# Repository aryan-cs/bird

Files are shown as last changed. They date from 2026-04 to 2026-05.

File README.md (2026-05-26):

# bird

revisiting one of my high school senior thesis projects

[[timf](https://aryan-cs.github.io/bird/timf.pdf)] [[rcgroup](https://www.rcgroups.com/forums/showthread.php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)] [[files](https://aryan-cs.github.io/bird)] [[repo](https://github.com/aryan-cs/bird)]

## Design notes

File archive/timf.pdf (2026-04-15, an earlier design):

# 3D Print F22 Raptor by TimF

Created | V1 | July 2021 | Original issue
Current Revision | V3 | 13th October 2022 | Scale shaping, tail reinforcements, sacrificial stab tips

A big thanks for your interest and for downloading this design

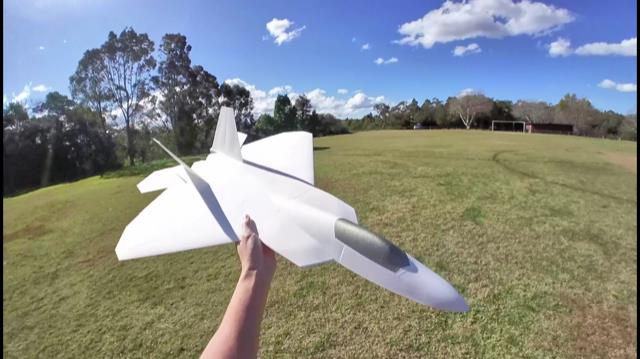
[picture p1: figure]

I’m a mechanical engineer and an RC enthusiast for over 30 years. I’ve also completed full-size pilot qualifications that have fallen to the side. Many dozens of kits later ranging from balsa and tissue, ARF’s, 3D prints to mass produced foamies, I’ve finally been able to get around to designing a plane. I hope it, and subsequent designs can help fulfill the dream of designing printing and flying your own planes.

The Raptor is an amazing subject. I can only imagine the design effort and championing that has gone into it. Lots of respect for this and the engineers that have contributed to its fruition. My rendition is purely for RC and as an enthusiast. I hope it can capture some of the real thing.

If you are familiar with RC planes (especially 3D printed ones), ahead is a relatively quick and easy print with a low part count. It is meant for intermediate to advanced flyers. With a dialled in printer, the fabrication happens in a week with little effort. Jet models can mean tiny wings, blindingly fast roll rate and a small shape which can be hard to fly. I have designed it from the outset to address as many of these traps as possible. Here is support documentation for the print, assembly, and setup as best I can provide to date for the best chances of success. Please do ask questions, make recommendations, or log any issues:

RC Groups thread: https://www.rcgroups.com/forums/showthread.php?3931791-F22-Raptor-700mm-LW-PLA#post47446455 (https://www.rcgroups.com/forums/showthread.php?3931791-F22-Raptor-700mm-LW-PLA#post47446455)

## Materials

1. PLA, LW-PLA (Colorfab, 3DLabPrint etc.) is preferred. A 1.75mm direct drive extruder printer is ideal
2. 50mm EDF. FMS 50mm, XRP-50mm, XFly-Model 4600kV or similar
3. 4s 1300mAh 25C or above battery
4. 350mm 0.87-1mm piano wire pushrod x 2
5. RC gear, quick pushrod linkages x 2
6. 250mm 3x1mm carbon main spar pultruded strip (x2) + 55mm (x2) for rear sub spars (optional)
7. 60mm OD3mm carbon taileron axle rod (x2) (or filled tube)
8. Adhesive Velcro j/o
9. 40A esc or above to suit EDF
10. 2x 9g servos (+2x 8mm thick servos if using flaperons)
11. Servo extension leads
12. Optional: 10mm dia.’ magnets for nose (x2)
13. Thin CA type hinges (optional)
14. 3x small servo mount type screws for fan hatch
15. Twist wire (from $2 shop or similar) or 1mm sharpened carbon fibre skewers to pin control surfaces

## Tools

1. Step drill bits (fine increment)
2. Hand twist drill or Dremel
3. Coarse round file or rasp to clean stringing
4. Sandpaper
5. Z bend pliers or needle nose pliers
6. Needle files
7. Hobby knife, hot knife
8. Side cutters
9. Metal ruler

## Adhesives

1. I use Acrifix ™ 0192 to glue PLA main assemblies and foamie Welder’s Glue™ or UHU-Por™ for spars etc.
2. Alternatively, medium CA plus accelerator as a rule throughout
3. Thin CA for wicking joints

## Print Overview, Definitions and Weights

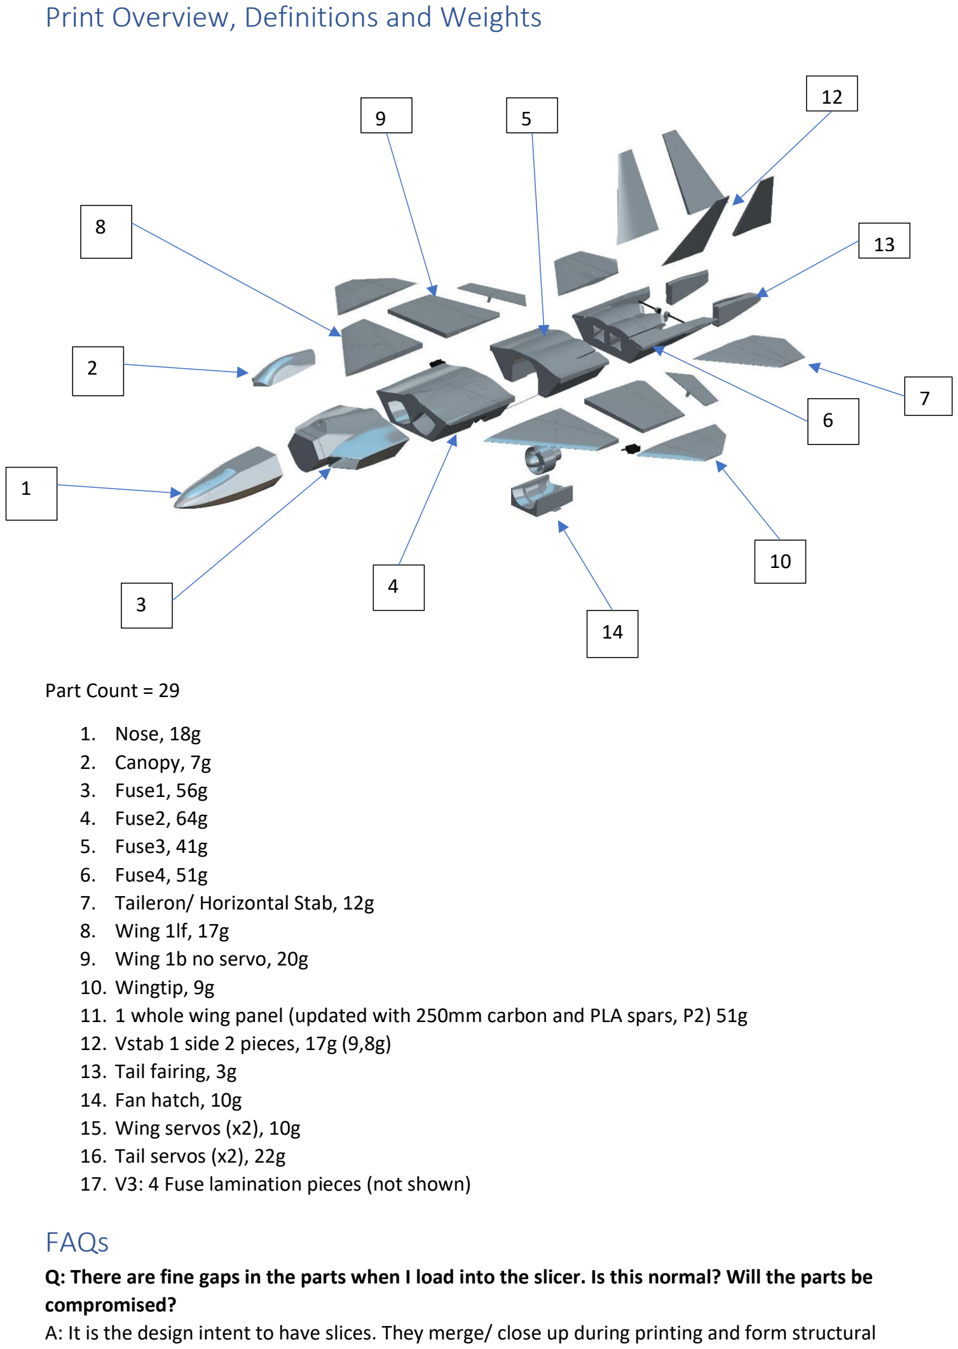
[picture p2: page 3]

Part Count = 29

1. Nose, 18g
2. Canopy, 7g
3. Fuse1, 56g
4. Fuse2, 64g
5. Fuse3, 41g
6. Fuse4, 51g
7. Taileron/ Horizontal Stab, 12g
8. Wing 1lf, 17g
9. Wing 1b no servo, 20g
10. Wingtip, 9g
11. 1 whole wing panel (updated with 250mm carbon and PLA spars, P2) 51g
12. Vstab 1 side 2 pieces, 17g (9,8g)
13. Tail fairing, 3g
14. Fan hatch, 10g
15. Wing servos (x2), 10g
16. Tail servos (x2), 22g
17. V3: 4 Fuse lamination pieces (not shown)

## FAQs

Q: There are fine gaps in the parts when I load into the slicer. Is this normal? Will the parts be compromised?
A: It is the design intent to have slices. They merge/ close up during printing and form structural

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
14 ribbing. If your extrusion is low, they will be more noticeable in the print. LW-PLA yields the best, strongest and lightest result as it foams, expands and merges during print. If unavoidable through print settings, run some thin CA glue in the gap and it will be even stronger

Q: Your parts look solid and un-usable

A: Slice with 0% infill (unless stated)

Q: The nose is a very tight fit

A: It is designed on the tight side in case some printers extrude differently and end up way too loose, so you might have to sand the corners slightly to achieve a snug fit. The material may relax a bit with use too so the intendent was to start off snug

Q: Which orientation to print the parts?

A: Refer to the table in printing section

## Configuration

There are 2 wing version:

1. Mandatory, 2 servos (i.e.: taileron/ elevon control)
2. Optional flaps + taileron 4 servos version. Flap to elevator mixing is in the radio control setup and throws section.

## Scaling

130%
If you want a slightly larger model, I have flown this model scaled up to 910mm wingspan, 1110g+battery weight.
1. 130% size in slicer program
2. 64mm EDF
3. 4S 2200 mAh Lipo
4. 4mm carbons in lieu of 3mm (solid rod is preferred over tube as handling damage can overtorque and split the carbon tubing)
5. 17g servos (30mm L) + 9g 8mm thick flap servos
6. 2% infill for wing 1f, horizontal stabs, wingtip, vstabs
7. Files from regular PLA version for wing 1r, horizontal stabs
8. Run fibre string through fuselage parts prior to joining to run servo cable extensions

## Printing

1. Print the parts with your best settings for LW-PLA/ PLA. LW-PLA is a foaming PLA material which is less than half the weight of standard PLA when printed properly. It has good layer adhesion due to expansion and foaming
2. Unless stated, print orientation for the parts is intended to be rear bulkheads/ wing root to build plate where possible. Look for any scribe lines which show where to cut after printing and align that surface to build plate
Part | Orientation (face) on print bed | Bottom Layers | Top layers
Sawtooth Nose | Rear | N | Y
Nose | Rear | N | Y

Fuse1 | Rear | Y | N
Fuse2 | Rear | Y | N
Fuse3 | Rear | Y | N
Fuse4 | Front | Y | Y
Wings | Root | Y | Y
Hatch | Front | Y | Y
Fairings | Inboard | Y | N
Tailerons | Root | Y | Y
Vertical Stabs | Rear and front | Y | Y
Flaps/ ailerons | Control horn | Y | Y
Hstab main | Root | Y | Y
HStab Front | Rear (rear, engraving down) | Y | Y
3. 2 walls of foaming LW-PLA. It is more expensive but worth using it as the parts are more resilient. You will get better results for your efforts, less transport damage and “tin canning” thanks to the extra wall
4. Narrow gaps-
5. If using regular non foaming PLA 1, wall is recommended as 2 walls will be too heavy
6. Good idea to start with the fan hatch print first off to check if your fan unit will need any cutting or wrapping with tape to fit in the bay
7. Print the rest of the parts starting with the nose, fuse1, 2. left wing, right wing etc.
8. The wing sections are very thin. Use an adhesive product such as Dimafix™ on the print bed or a brim to ensure they don’t get knocked over. The aileron CAD has been supplied with adhesion tabs to help. Trim these off with side cutters after printing
9. 0.4mm ‘Z hop when retracted’ to allow expansion flow and avoid knocking parts over
10. 0% infill unless essential or printing the 64mm version
11. Clean any stringing as much as possible with a rasp or long metal ruler edge
12. Parts that need knifing/ hot wire cutting afterward have the paths scribed/ indented. They are important for cable routing. Heat a wire and use it to cut the excess panel out or use several careful light cuts with a scalpel. Don’t forget, as it is a pain to do this afterwards
13. The taileron horns require a slight cooler printing temp (if using LW-PLA) to have less foaming effect and greater hardness/ precision. I use 220-225°C. as opposed to 230°C for the airframe

## Assembly

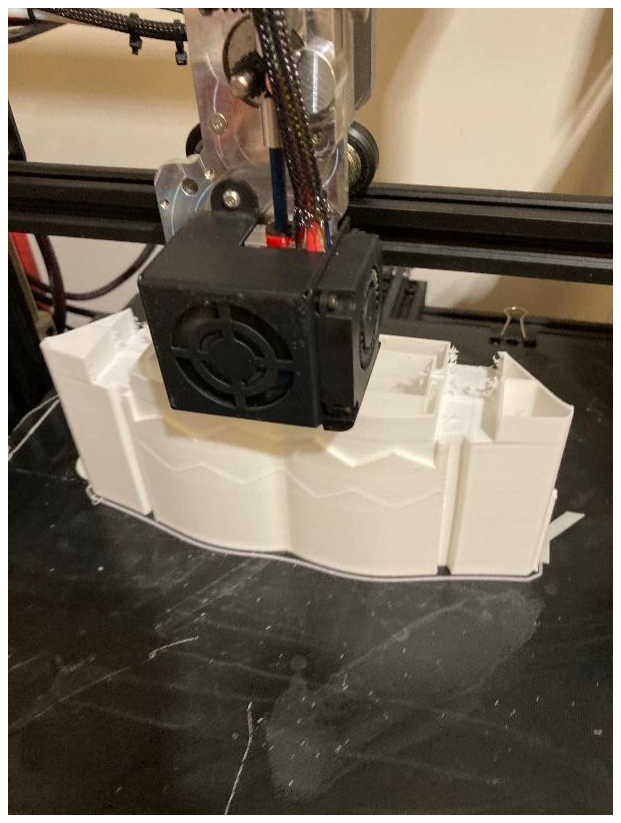
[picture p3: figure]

Start the fuselage assembly whilst the wings are printing.

1. Starting with the Fan hatch and Fuse3, cut open the motor wire and servo openings with a hot knife. Check your EDF fan unit fits. Wrap with masking tape/ cut plastic if needed. Install the unit in with UHU Por or Welders glue
2. Plug in the ESC, route the cables and ESC forward and make sure the fan spins in the correct direction when powered up (it should also be balanced for best results). Screw down the fan hatch. That’s the engine installation done!
3. Cut the marked cable routing panels for Fuse 2 out of the bottom and have the part ready
4. Cut 2x 250mm of the 0.81mm piano pushrod wire and thread it through the pushrod guides of Fuse 2 and Fuse 3. Make sure it slides freely. Use it as an alignment aid to help glue the fuse together (Medium CA or Acrifix). Don’t use excessive glue, and don’t glue the fan hatch to Fuse 2!

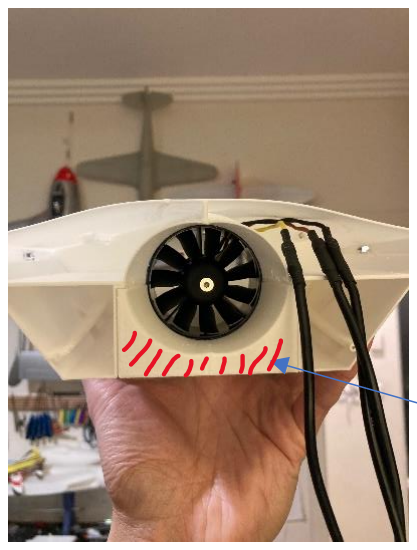
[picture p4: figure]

5. Glue Fuse 4 using the same method

No glue!

6.

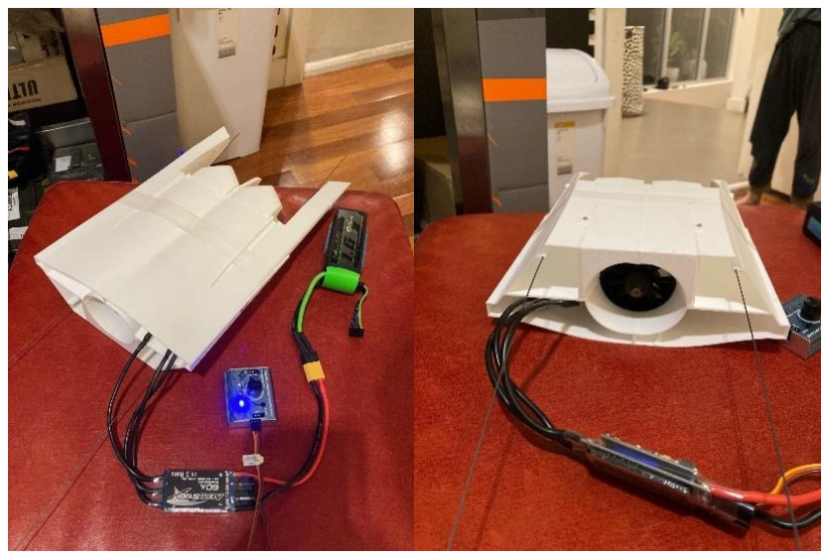
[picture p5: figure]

7. Cut routing holes and glue Fuse 1
8. Paint and attach the canopy to the nose or set painted canopy aside for later. Friction fit to Fuse 1 should be enough but install the optional magnets if needed. Tape can also be used to retain the nose. File the corners of Fuse 1 neck if needed

The taileron/ horizontal stabilizer assembly starts from the pushrod and works its way out to the control surface:

9. Chip away at one objective per night. Sleep, and it will come together
10. Make a “Z” or “L” bend on the pushrod wire ends exiting Fuse 4
11. Glue the horn lamination onto the taileron horn. Once dry, clean the pushrod holes with a step drill bit and assemble the Z bend into the outermost hole of the horn
12. New V3: glue the lamination plates to the cantilever tail forks. This will reduce the chance of the bearings shattering if your elevons get caught on grass
13. Check that the 3mm carbon torque tubes pivot freely in the bearings of Fuse4 with no slop. Some filing or drilling might be needed
14. With the torque tube in the bearing of Fuse4, press fit the laminated horn assembly (with wire pushrod attached) onto the end of the torque tube. The horn lamination top surface should be flush with the end of the carbon tube
15. Use a sharp micro step drill to drill across the horn and carbon torque tube. Push some lock wire or 1mm carbon skewer through the hole to lock the assembly. When satisfied, back the whole torque rod assembly out of the bearing slightly and carefully apply 2 small drops of thin CA to fix. Hit with accelerator to make sure it is all cured overnight and won’t accidentally be glued to the bearing. It’s important to have a smooth and slop free linkage here, so start over if it goes badly

16.

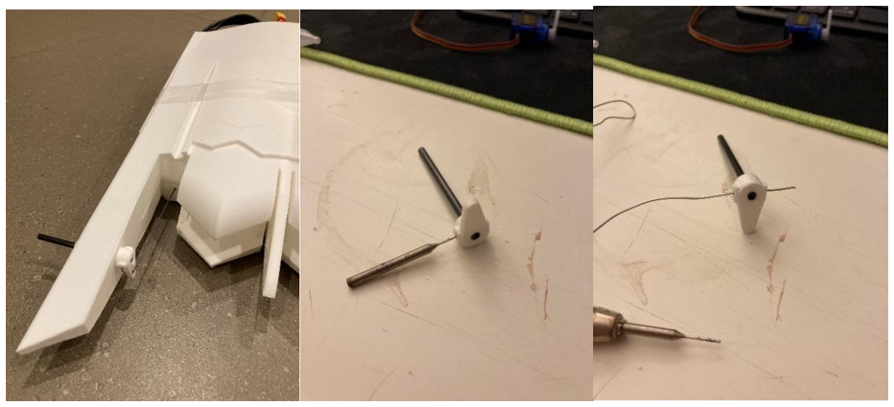
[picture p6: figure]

Pics show axle taken out for clarity)
17. Press fit the horizontal stab onto the axle. Use a sharp drill bit and drill through the stab guide holes and axle and use 1mm carbon skewer and thin CA to lock in
18. Wing: Glue Wing l1f to l1b. Let dry. Cut 250mm of the 3x1 carbon strip and sharpen one end. Use it to clear the spar hole and then glue the wing tip. Check spar final fit and repeat for right wing. Wings are done!
19. Once the control surfaces are done and working smoothly, glue the fairings to cover up the linkages and strengthen the tail. UHU Por the fairing or tack glue in case it needs to be serviced later.
20. Glue the fin halves
21. Glue the spars into the wings with Welder’s or UHU glue, inject some into the spar holes first
22. Glue wings to fuselage (note there are positions for rear spars) and the airframe is done
23. Install all the RC gear with servo lead extensions
a. If you use quick links with grub screws on the servo end, ensure they have adequate Locktite on the pushrod and grub screw tip. More is better. The taileron pushrods can experience strong pull force in dives and landing mishaps have occurred (catching grass). They can pull out of your servos if not secure and cause a loss of control. A z-bend is better if you can form one at the servo end
24. Stick self-adhesive Velcro on the battery bay tray
25. Congrats! Your Raptor is assembled

## Mandatory CG Check and Pre-Flight

1. The CG is located at 22.6% of the wing chord from the wing leading edge (87mm from the leading edge). This coincides with the front edge of the servo hole openings. CG is also at the front edge of servo openings for the 130% version.

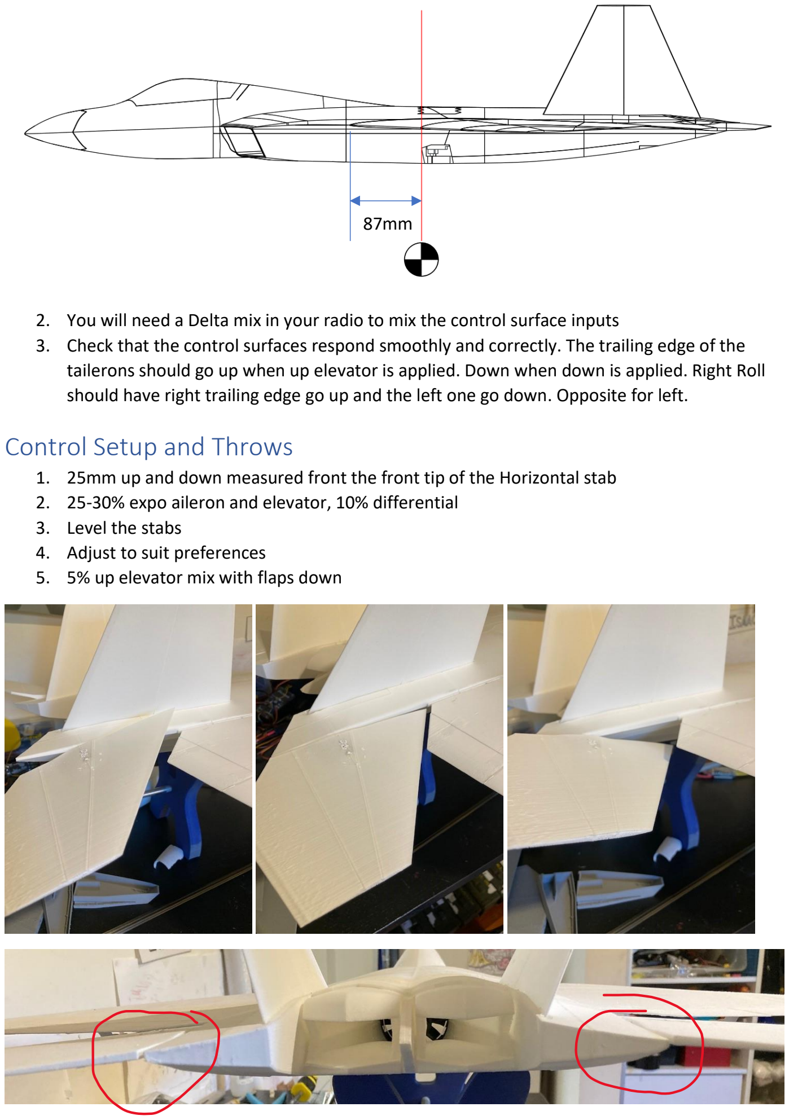
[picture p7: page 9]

2. You will need a Delta mix in your radio to mix the control surface inputs
3. Check that the control surfaces respond smoothly and correctly. The trailing edge of the tailerons should go up when up elevator is applied. Down when down is applied. Right Roll should have right trailing edge go up and the left one go down. Opposite for left.

## Control Setup and Throws

1. 25mm up and down measured front the front tip of the Horizontal stab
2. 25-30% expo aileron and elevator, 10% differential
3. Level the stabs
4. Adjust to suit preferences
5. 5% up elevator mix with flaps down

87mm

## Flying Tips

1. Do your pre-flight checks! Make sure the linkages are tight and working smoothly
2. Finger grips have been designed near the CG to help grip the model. The centre hole is a cutout to allow hanging the model up on the wall easily
3. The model is meant to be hand-launched. As with most jet models a good level throw is needed, slightly nose up (no more than 10 degrees)

4.

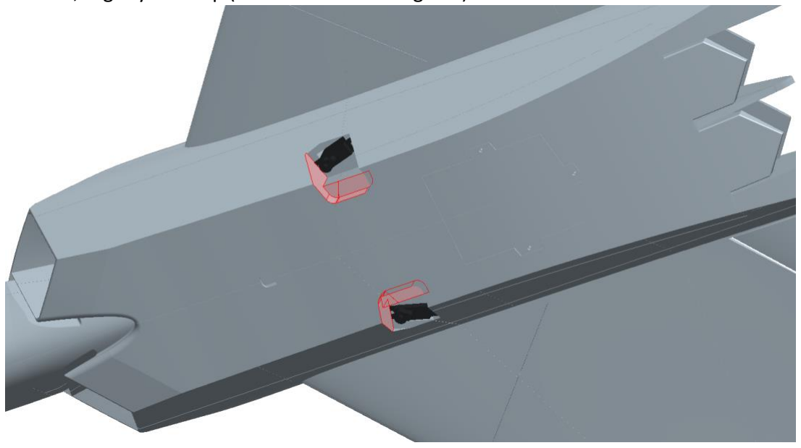
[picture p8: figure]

5. Relax up elevator upon touchdown… The elevator tips can catch rutty terrain if you hold the flare like a taildragger resulting in torn up elevators, linkages, or servos. The throws are less than the fuselage extremities, but grass can get stuck in the gaps. Relax the elevator to be safe. Sacrificial elevator tips are on the cards if beneficial.

Best of luck. Safe and happy flying!

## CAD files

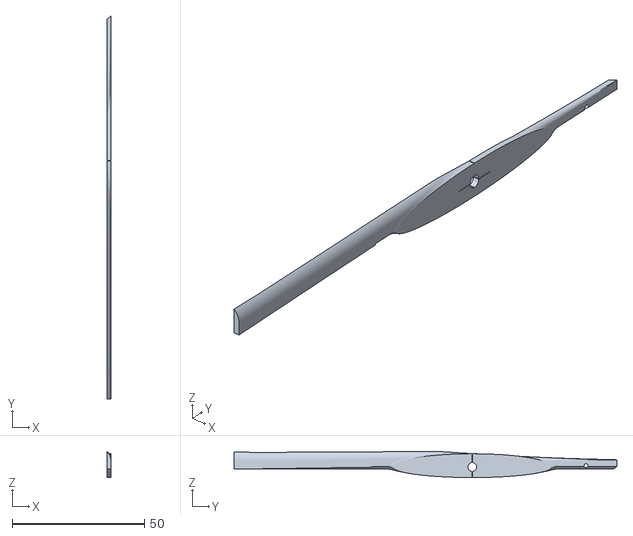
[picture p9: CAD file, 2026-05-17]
jet/LW-PLA/F22_Raptor_Fuselage/f22_raptor_fuse_4_laminate_l.stl
1.60 x 144.7 x 9.87

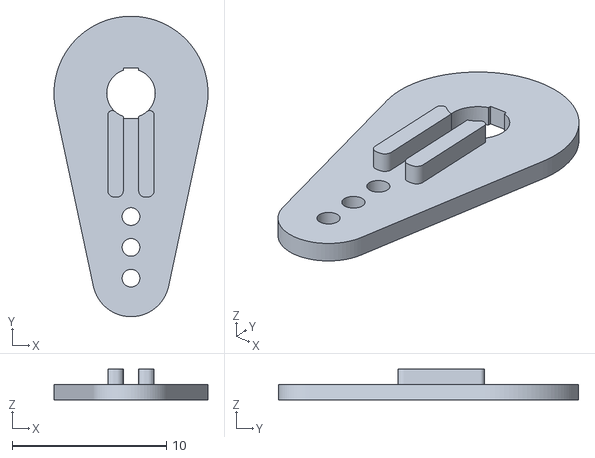
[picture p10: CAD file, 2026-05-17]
jet/LW-PLA/F22_Raptor_HStab/f22_raptor_horn_lamination.stl
10.00 x 19.5 x 2.00

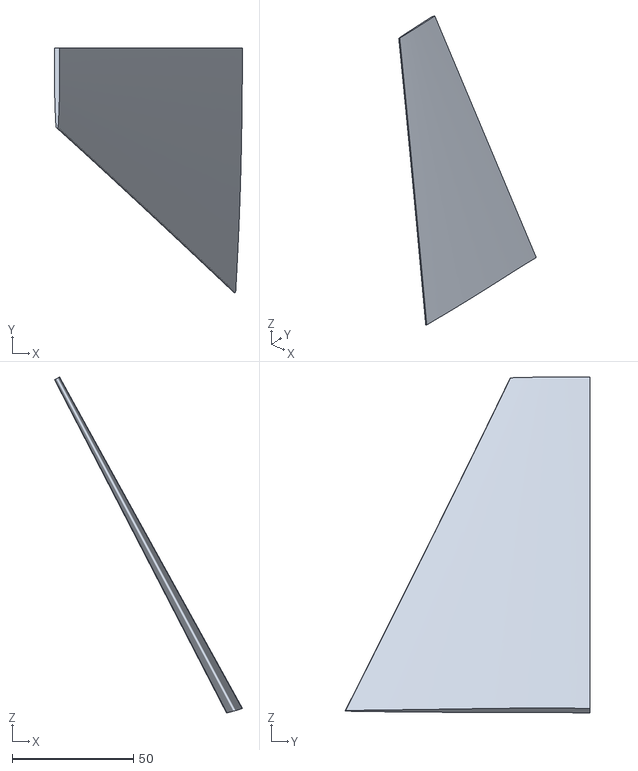
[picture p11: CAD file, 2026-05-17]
jet/LW-PLA/F22_Raptor_VStab/f22_raptor_vstab_r.stl
77.6 x 101.0 x 138.7

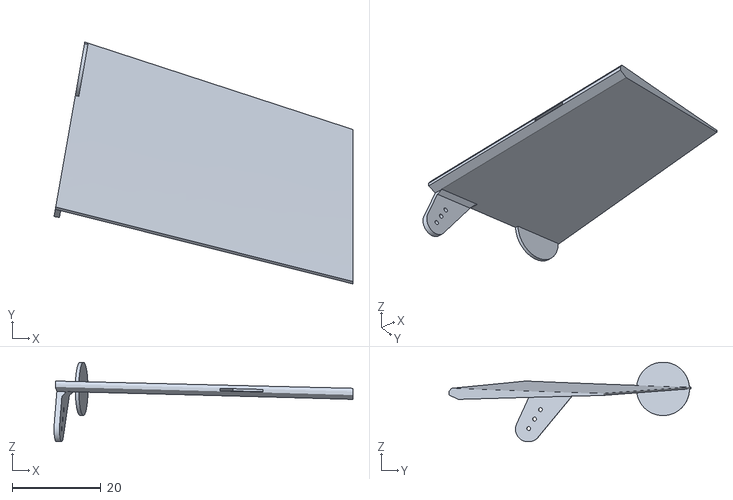
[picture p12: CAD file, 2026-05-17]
jet/LW-PLA/F22_Raptor_Wings/F22_Raptor_Wing_Left/f22_raptor_l_ail_outer.stl
67.4 x 54.5 x 17.9

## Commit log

2026-05-17 add f22_raptor_horn_lamination.stl
    [f22_raptor_horn_lamination.stl]
2026-05-17 add f22_raptor_l_ail_outer.stl
    [f22_raptor_l_ail_outer.stl]
2026-05-17 add f22_raptor_fuse_4_laminate_l.stl
    [f22_raptor_fuse_4_laminate_l.stl]
2026-05-17 add f22_raptor_vstab_r.stl
    [f22_raptor_vstab_r.stl]
2026-05-17 add f22_raptor_fuse_1.stl
2026-05-17 add f22_raptor_nose_cone.stl
2026-05-17 add f22_raptor_fuse_2_lowfloor.stl
2026-05-17 add f22_raptor_fuse_2.stl
2026-05-26 Add Three.js STL viewer for GitHub Pages
    - docs/viewer.html: interactive Three.js STL viewer (orbit, wireframe,
    auto-rotate). Fetches STLs from jsDelivr with raw.githubusercontent.com
    fallback. URL pattern: viewer.html?stl=<path>.
    - docs/index.html: browseable index of every STL in the repo, grouped by
    airframe section. Highlights the twin-EDF modified parts.
    - docs/404.html: catches any .stl URL under /bird/ and redirects to the
    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
2026-05-26 Add twin-EDF conversion: parametric build123d ducting + modified STLs
    Reworks Fuse 2/3/4 to hold two 50 mm EDFs side-by-side instead of TimF's
    single-EDF design:
    - Fuse 2: two intake channels stay separate (no merger)
    - Fuse 3: two parallel 52 mm bores for the EDFs
    - Fuse 4: two ducts merge into a single rectangular exhaust nozzle
    Pipeline (run `python twin_edf/src/generate.py`):
    1. inspect_stl.py - read TimF's STLs, dump bbox + per-Y cross-sections
    2. ducting.py - parametric build123d air-channel volume
    3. generate.py - per-Y outer envelope (tighter than convex hull) +
    boolean subtract ducts -> modified STLs + STEP
    4. compare_sections.py / ren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
    [fuse2_modified.stl, fuse2_new_ducts.step, fuse2_new_ducts.stl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]
2026-05-26 Strip subtitle/chips/footer from index, remove twin_edf modified files
    - index.html: keep only "bird" title and the file grid; drop the tag chip,
    intro paragraph, section pill chips, and explanatory footer.
    - Delete twin_edf/ — modified STLs and parametric ducting work were not
    what was wanted on the public site.
    [fuse2_modified.stl, fuse2_new_ducts.step, fuse2_new_ducts.stl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]
2026-05-26 Viewer: recenter mesh at world origin, drop axes helper
    TimF's STLs use a global fuselage coordinate frame (each Fuse part sits at
    a different Y range), so parts loaded into the viewer were offset from the
    grid. Recenter the geometry at origin on load so the grid sits directly
    under the part. Also remove the AxesHelper — it pointed at the bbox corner
    and added clutter without orientation value for an isolated-part viewer.
2026-05-26 Add jet/assembled.stl — all parts merged into one in assembly position
    TimF's STLs share a single global coordinate frame, so all 25 main parts
    (fuselage stack, wings, taileron, vstabs, fan hatch, horn covers,
    ailerons) merge into a complete F-22 with no manual placement needed.
    Per-part quadric decimation keeps the result at ~742k triangles / 37 MB,
    under jsDelivr's 50 MB cap so the Pages viewer can stream it. Index has
    a new "Assembled" entry at the top.
2026-05-26 Rename assembled.stl -> f22.stl, fix orientation, drop accent color
    - Rotate -90° about X so TimF's longitudinal/Y maps to three.js +Z and the
    vertical tail rises along three.js +Y. Previously the jet rendered
    vertical and upside-down because TimF's Z-up frame mismatched three.js's
    Y-up default.
    - merge_vertices + unique_faces pass after concatenation to clean up the
    geometry, reducing the visible "wireframe noise" from z-fighting at
    part-to-part interfaces.
    - Drop the purple "twin" tint from the Assembled section so it matches
    the rest of the index.
2026-05-26 f22.stl: rebuild as one watertight outer shell via voxelize+remesh
    Previous approach (concatenate decimated parts) left every internal wall
    and every back-of-skin face visible because three.js renders DoubleSide
    by default — the jet looked like wireframe noise as soon as you assembled
    multiple parts.
    New pipeline:
    1. Voxelize each part at 2 mm pitch into a shared global grid
    2. Union all part voxel sets
    3. Marching cubes -> single watertight outer surface
    4. Quadric-decimate to 350k tris
    5. Rotate -90° about X for three.js Y-up
    Result is a clean 17.5 MB watertight F-22 outline. Internal duct walls,
    mate caps, wing-root tabs, etc. are all inside the filled voxel volume
    and gone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
2026-05-26 Assembled view: load original parts as multiple meshes via JSON manifest
    The voxel+remesh approach for jet/f22.stl produced visible cubic artifacts
    when zoomed in (1 mm pitch + Taubin smoothing wasn't fine enough). The
    boolean-union approach failed because TimF's parts are thin shells, not
    volumes.
    Solution: render each original part directly in three.js, no merging.
    Parts share TimF's global coordinate frame, so they assemble naturally
    as separate meshes in one scene — each at its native smooth resolution.
    - Added jet/f22.json: manifest listing the 25 canonical part paths.
    - viewer.html: detects .json URLs as manifests, fetches each STL in
    parallel, adds to a Group, rotates -90° X fo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
2026-05-26 Index: derive file extension chip from filename
    Hardcoded ".stl" was wrong for jet/f22.json. Now reads the extension
    from each file's name so .json shows as ".json" and .stl shows as ".stl".
